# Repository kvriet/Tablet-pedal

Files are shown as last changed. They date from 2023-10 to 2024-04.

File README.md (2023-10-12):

# Tablet Foot Pedal
A foot pedal for a tablet for hands-free page turning.

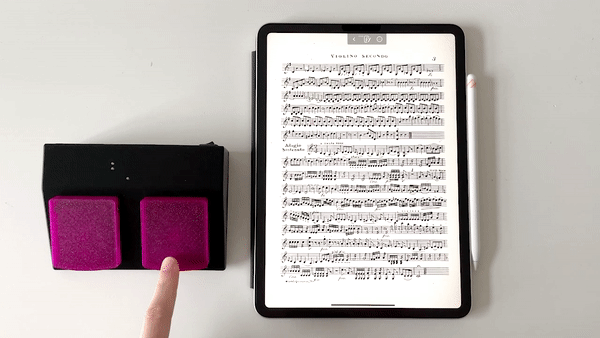
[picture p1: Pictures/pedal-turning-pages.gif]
Foot pedal connected to tablet turning pages of sheet music


## Instructions
### Pairing
The pedal has a power switch that turns on the pedal and automatically puts it in bluetooth pairing mode. When the pedal is turning on, the blue LED will flash rapidly three times. For first-time pairing, open the bluetooth menu on your sheet music device, select your pedal (Pedal Name) and agree to pair. That's all that is needed. On most devices pairing will be automatic after that.

### Power and sleep mode
To conserve energy, turn the pedal off with the black power switch when you're not using the pedal for a longer time. If you forget to switch it off, the pedal will go into deep sleep after 15 minutes. To wake the pedal up again, turn it off and on with the power switch.

How many minutes it takes before the pedal goes to sleep can be changed in the code with the timeUntilSleepMins variable.

On a single full charge, the battery should last roughly 12 hours of use.

### Low battery warning
When the battery is running low, the pedal will flash the blue LED rapidly four times. It does this every minute.
This feature can be disabled in the code by setting lowBatteryMessage to 'false'.

### Charging
The pedal runs on a 3100mAh, 18650 Li-ion battery. The battery can be charged via the micro-USB port using a common USB phone charger. When charging, the red LED will turn on. Once charging is done, the green LED will turn on.

Safety: The pedal contains a protection circuit for the battery to prevent charging and discharging too much. However, always take care with Li-ion batteries. It's best to charge them where you can keep an eye on them. For good battery health, don't leave the battery discharged for many months. Don't use the pedal in environments below 0 degrees Celsius.

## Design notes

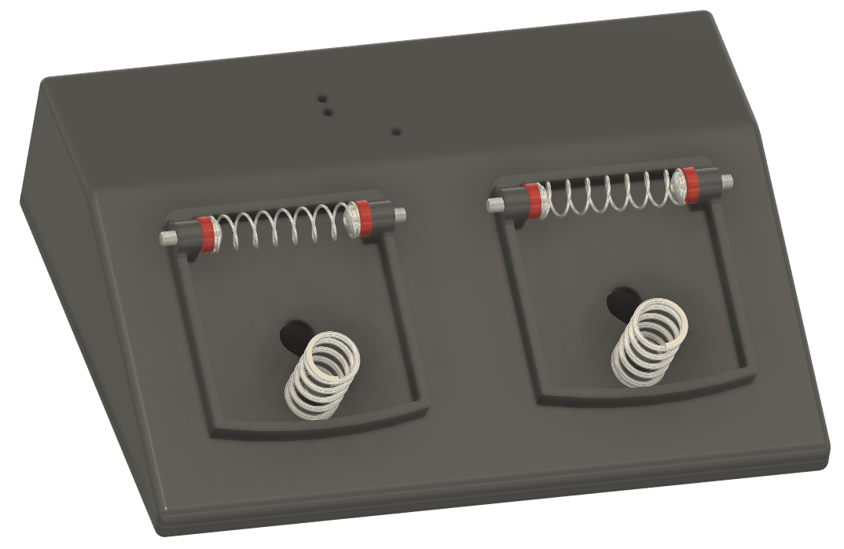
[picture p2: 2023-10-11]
Pictures/turner-without-pedals-springs-visible.png

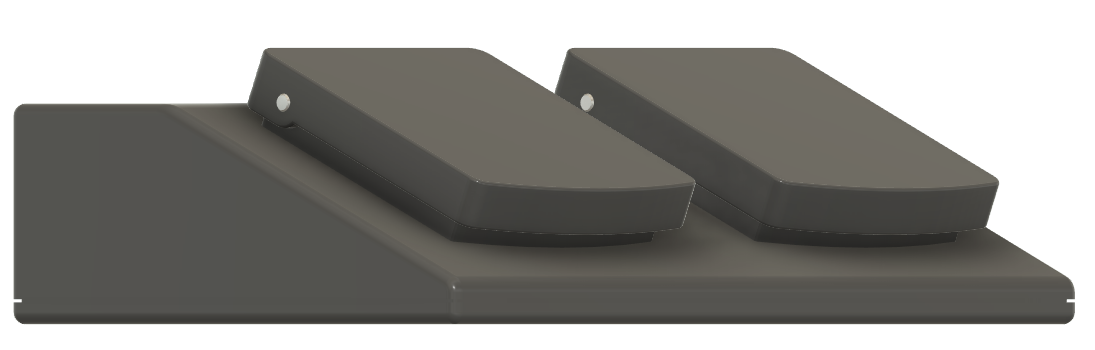
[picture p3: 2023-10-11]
Pictures/turner-corner-view-pedals.png

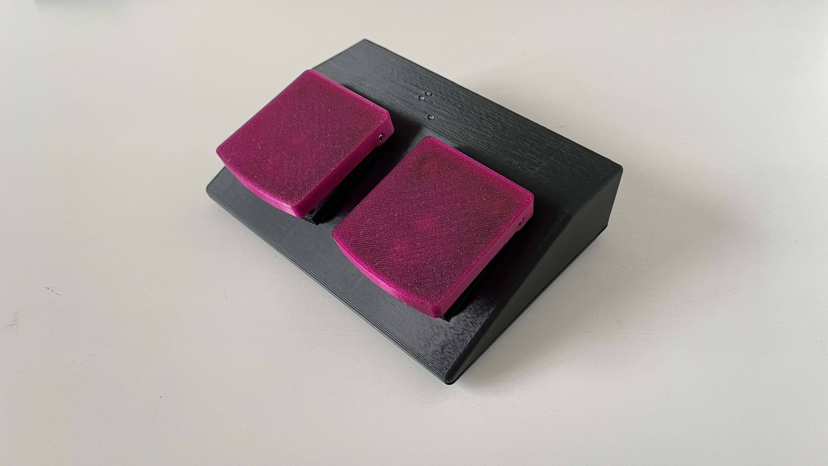
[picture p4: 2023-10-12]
Pictures/page-turner.JPG

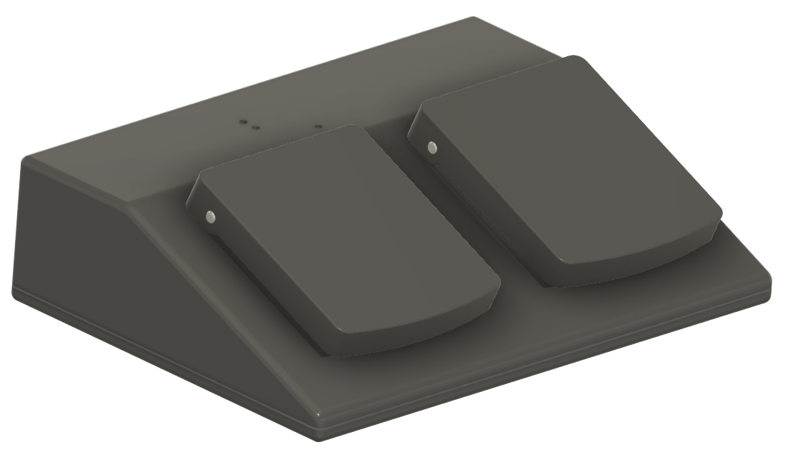
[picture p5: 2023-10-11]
Pictures/page-turner.png

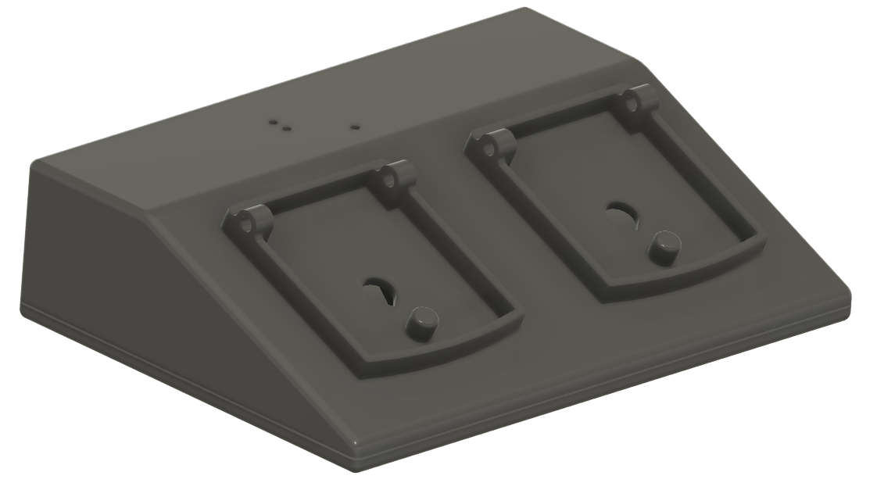
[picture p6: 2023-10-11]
Pictures/page-turner-no-pedals-no-springs.png

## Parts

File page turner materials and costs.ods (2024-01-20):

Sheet: Costs
amount | name | item | total | link to item
1 | LilyGO TTGO T-Energy ESP32-WROVER | € 8.00 | € 8.00 | https://www.aliexpress.com/item/4000453570320.html, https://www.tinytronics.nl/shop/nl/development-boards/microcontroller-boards/met-wi-fi/lilygo-ttgo-t-energy-esp32-wrover-met-18650-batterijhouder
1 | 18650 Li-ion battery | € 3.50 | € 3.50 | https://www.tinytronics.nl/shop/nl/power/batterijen/18650/eve-18650-li-ion-batterij-3100mah-10a-inr18650-33v
2 | buttons for pedal left and right Normally Open | € 0.36 | € 0.72 | https://nl.aliexpress.com/item/4000208544567.html
2 | springs 6mm x 30mm 0.6mm diameter | € 0.09 | € 0.17 | https://nl.aliexpress.com/item/1005001408318647.html
2 | springs 8mm x 20mm 0.8mm diameter | € 0.09 | € 0.18 | https://nl.aliexpress.com/item/1005001408406253.html
1 | rocker switch 8.5 x 13.5mm | € 0.45 | € 0.45 | https://www.tinytronics.nl/shop/nl/schakelaars/manuele-schakelaars/wipschakelaars/standaard-inbouw-wipschakelaar-klein
4 | screws 3mm x 10mm | € 0.03 | € 0.11 | https://www.tinytronics.nl/shop/nl/gereedschap-en-montage/installatie-en-montagemateriaal/bouten/bout-m3-10mm-draad-100-stuks
7 | screws 3mm x 5mm | € 0.03 | € 0.18 | https://www.tinytronics.nl/shop/nl/gereedschap-en-montage/installatie-en-montagemateriaal/bouten/bout-m3-5mm-draad-100-stuks
124 | filament (grams) | € 0.02 | € 2.60 | https://www.tinytronics.nl/shop/nl/3d-printen/filament/1.75mm-filament/pla/azurefilm-pla-filament-1.75mm-1kg-zwart
4 | silicone feet | € 0.02 | € 0.07 | https://www.aliexpress.com/p/shoppingcart/index.html
 |  | total | € 15.97
 |  |  |  | Picture and schematic of pushbutton (from TinyTronics):

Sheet: Sign_up
Jack
Daan

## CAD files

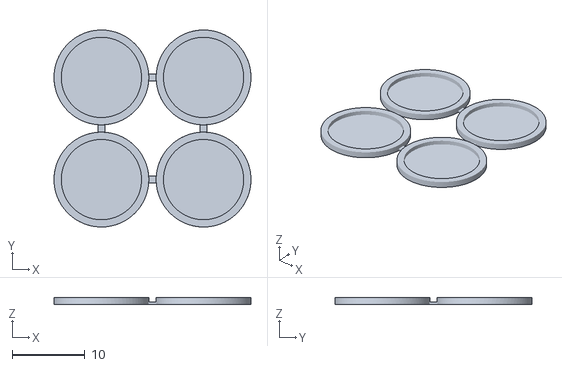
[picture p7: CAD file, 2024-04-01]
Print files/4x 10mm feet.stl
27.0 x 27.0 x 0.9

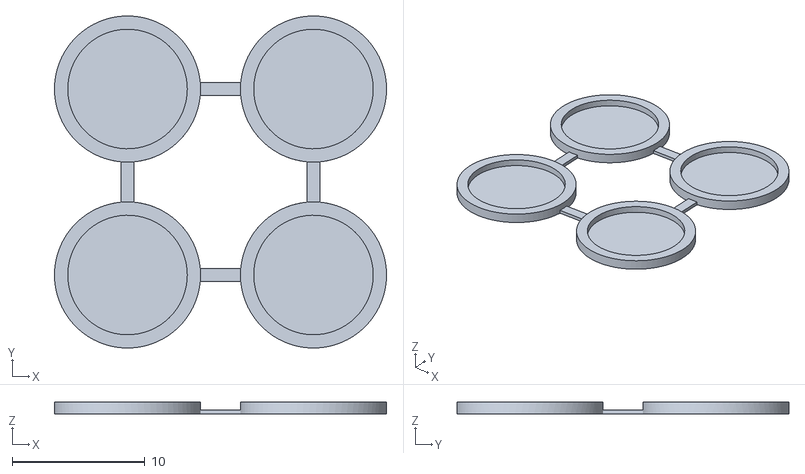
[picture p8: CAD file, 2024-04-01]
Print files/4x 8mm feet.stl
25.0 x 25.0 x 0.9

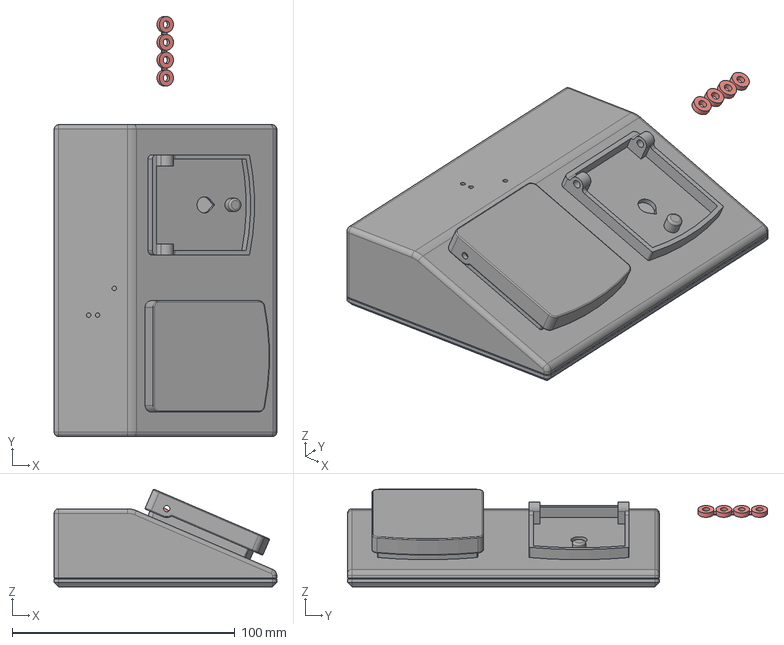
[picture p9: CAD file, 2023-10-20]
Print files/page turner STEP file.step
100.0 x 188.6 x 43.8 mm

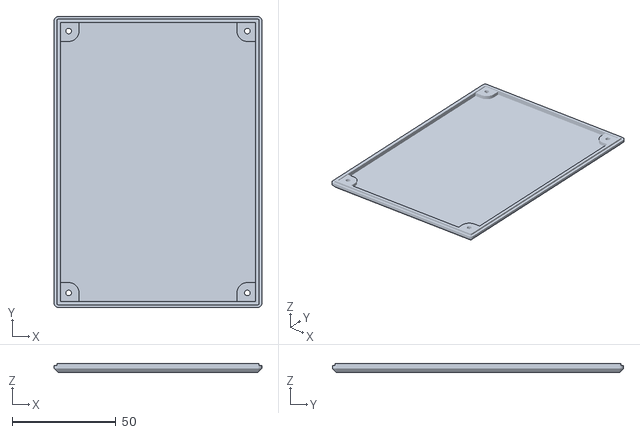
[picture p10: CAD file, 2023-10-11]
Print files/page turner bottom v3.stl
100.0 x 140.0 x 4.50

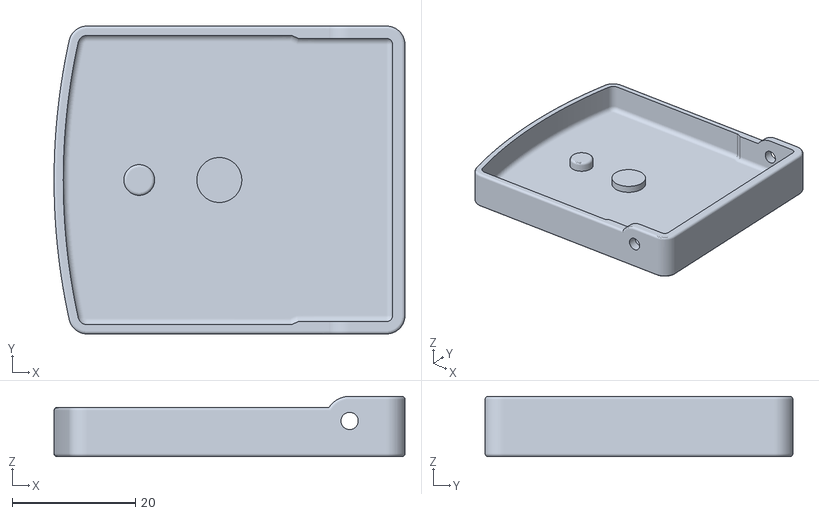
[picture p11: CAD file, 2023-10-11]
Print files/pedal v4.stl
57.0 x 50.0 x 9.80

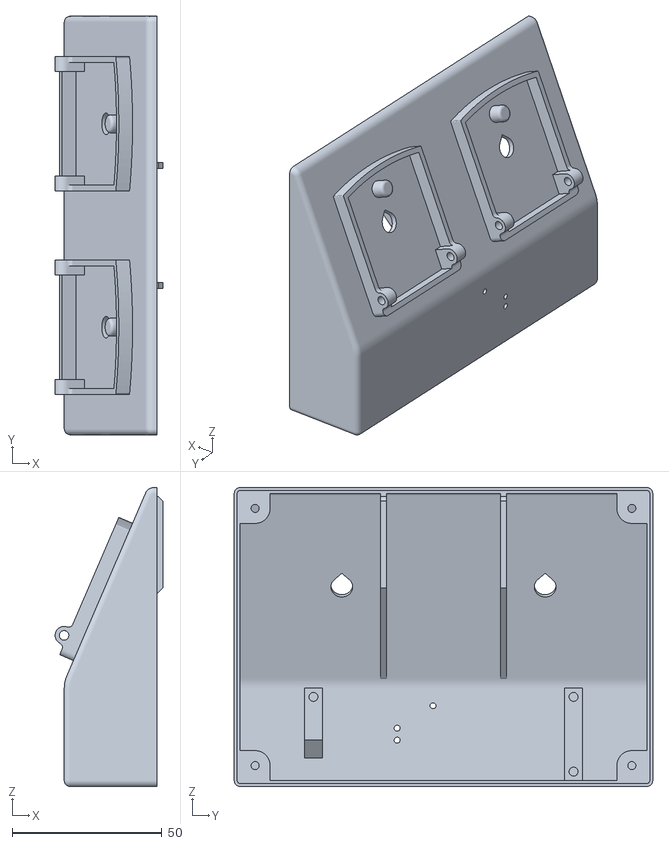
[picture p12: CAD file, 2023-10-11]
Print files/page turner top v4.stl
36.1 x 140.0 x 100.0

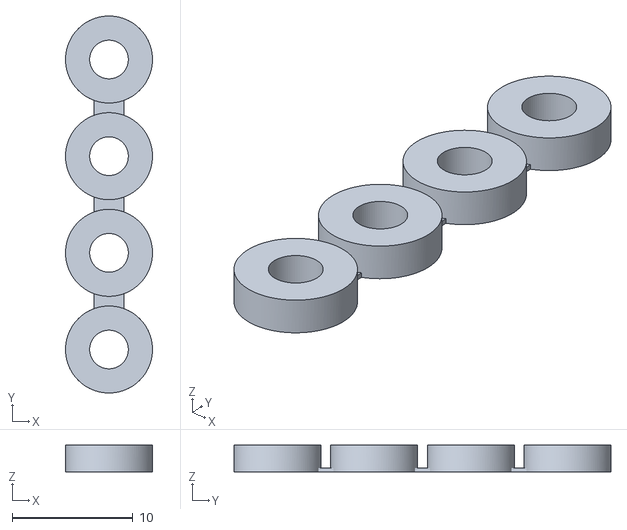
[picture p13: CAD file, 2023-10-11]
Print files/axle washer 3.4mm 4x strip v2.stl
7.20 x 31.2 x 2.20

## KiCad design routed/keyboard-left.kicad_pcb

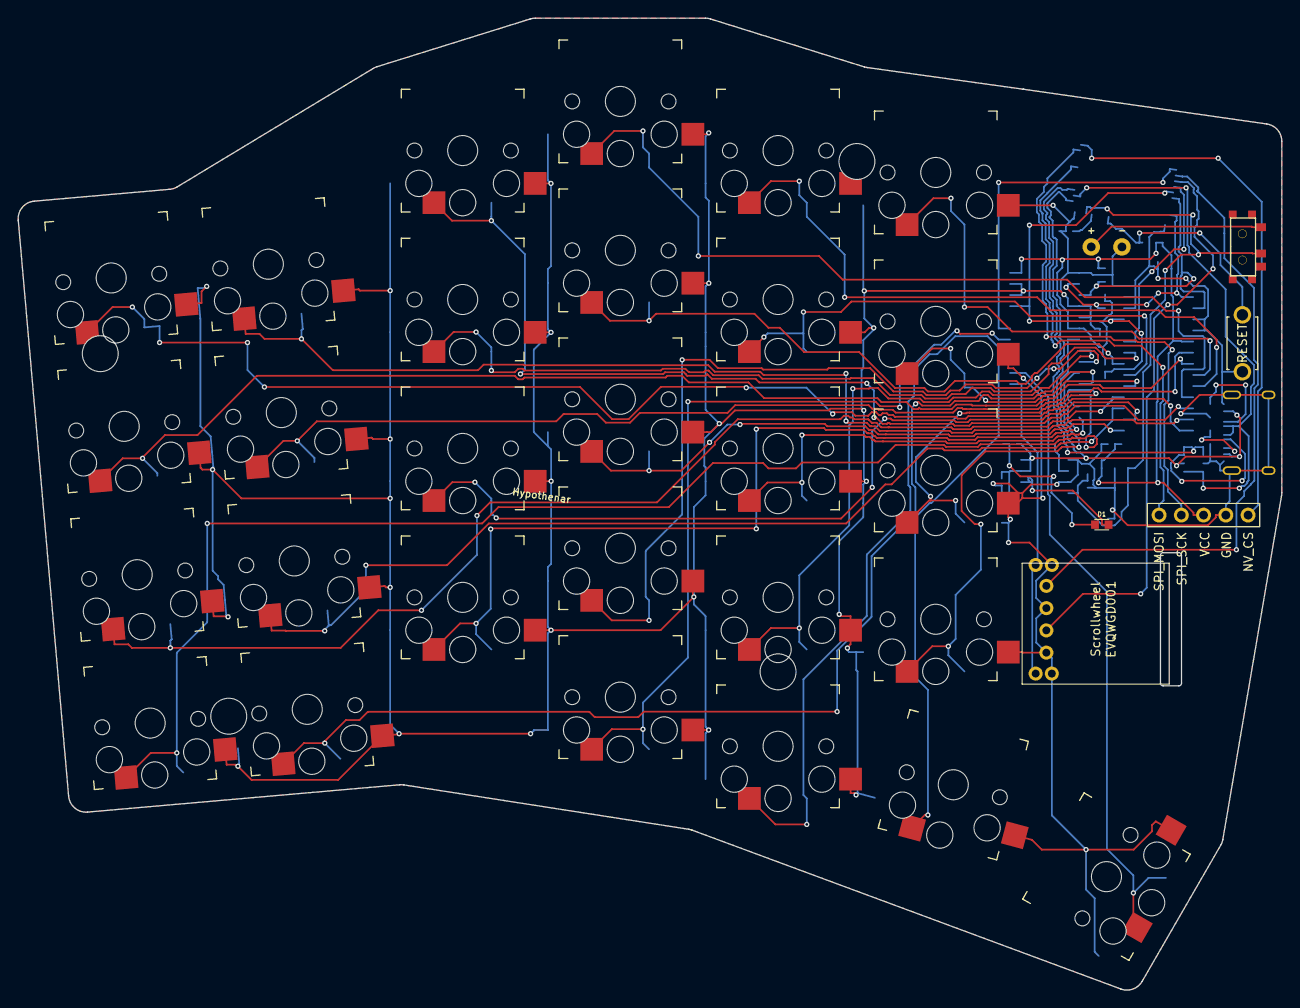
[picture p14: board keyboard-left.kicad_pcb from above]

Board: 2 copper layers, 144.2 x 110.9 mm, 60 parts (0 on the bottom side), 50 nets.

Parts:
19.051: ms88sf3
19.052, 19.053: MCP23017; MCP23017_SOIC-28W
19.054: USB_C_Receptacle_HRO_TYPE-C-31-M-12
19.055: USBLC6-2SC6; USBLC6-2SC6_SOT-23-6
19.056: TP4056; TP4056_SOP-8
19.057: XC6206P332MR; XC6206_SOT-89-3
BT1: BATTERY; battery_pads
DISP1: display_nice_view
P1: C1; passive_0603
P2: C2; passive_0603
P3: C3; passive_0603
P4: C4; passive_0603
P5: C5; passive_0603
P6: C6; passive_0603
P7: C7; passive_0603
P8: C8; passive_0603
P9: R1; passive_0603
P10: R2; passive_0603
P11: R3; passive_0603
P12: R4; passive_0603
P13: R5; passive_0603
P14: R6; passive_0603
P15: R7; passive_0603
P16: R8; passive_0603
P17: D1; passive_0603
S1, S2, S3, S4, S5, S6, S7, S8, S9, S10, S11, S12, S13, S14, S15, S16, S17, S18, S19, S20, S21, S22, S23, S24, S25, S26, S27, S28: PG1350
T1: SPDT_C128955
_1: ResetSW
_2, _3, _4, _5: Hole

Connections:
CHARGE_ACTIVE: 19.056.6, P17.2
CHG_LED: P16.2, P17.1
GND: 19.051.1, 19.051.18, 19.051.34, 19.052.10, 19.052.11, 19.052.14, 19.052.15, 19.052.16, 19.052.17, 19.053.10, 19.053.11, 19.053.14, 19.053.16, 19.053.17, 19.054.A1, 19.054.A12, 19.054.B1, 19.054.B12, 19.054.SH, 19.055.2, 19.056.1, 19.056.3, 19.057.2, BT1.2, DISP1.4, P1.2, P2.2, P3.2, P4.2, P5.2, P6.2, P7.2, P8.2, P11.2, P12.2, P13.2, S1.2, S2.2, S3.2, S4.2, S5.2, S6.2, S7.2, S8.2, S9.2, S10.2, S11.2, S12.2, S13.2, S14.2, S15.2, S16.2, S17.2, S18.2, S19.2, S20.2, S21.2, S22.2, S23.2, S24.2, S25.2, S26.2, S27.2, S28.2, _1.2
I2C_RESET: 19.051.13, 19.052.18, 19.053.18, P14.2
I2C_SCL: 19.051.14, 19.052.12, 19.053.12, P9.2
I2C_SDA: 19.051.17, 19.052.13, 19.053.13, P10.2
MCP_A_INT: 19.051.12, 19.052.20
MCP_B_INT: 19.051.9, 19.053.20
NV_CS: 19.051.45, DISP1.5
PROG: 19.056.2, P13.1
RESET: 19.051.28, P15.2, _1.1
SPI_MOSI: 19.051.41, DISP1.1
SPI_SCK: 19.051.44, DISP1.2
USB_CC1: 19.054.A5, P11.1
USB_CC2: 19.054.B5, P12.1
USB_DM: 19.051.36, 19.054.A7, 19.054.B7, 19.055.3, 19.055.4
USB_DP: 19.051.37, 19.054.A6, 19.054.B6, 19.055.1, 19.055.6
VBAT: 19.051.32, 19.056.4, 19.057.1, P3.1, P4.1, T1.2
VBAT_SW: BT1.1, T1.1
VBUS: 19.051.35, 19.054.A4, 19.054.A9, 19.054.B4, 19.054.B9, 19.055.5, 19.056.7, 19.056.8, P1.1, P2.1, P16.1
VCC: 19.052.9, 19.053.9, 19.053.15, 19.057.3, DISP1.3, P5.1, P7.1, P8.1, P9.1, P10.1, P14.1, P15.1
VDD_MCU: 19.051.31, P6.1
sw_matrix_index_bottom: 19.053.7, S19.1
sw_matrix_index_home: 19.053.1, S20.1
sw_matrix_index_mod: 19.053.22, S18.1
sw_matrix_index_num: 19.052.5, S22.1
sw_matrix_index_top: 19.052.23, S21.1
sw_matrix_inner_bottom: 19.053.8, S23.1
sw_matrix_inner_home: 19.053.2, S24.1
sw_matrix_inner_num: 19.052.6, S26.1
sw_matrix_inner_top: 19.052.24, S25.1
sw_matrix_middle_bottom: 19.053.6, S14.1
sw_matrix_middle_home: 19.052.28, S15.1
sw_matrix_middle_mod: 19.053.21, S13.1
sw_matrix_middle_num: 19.052.4, S17.1
sw_matrix_middle_top: 19.052.22, S16.1
sw_matrix_outer_bottom: 19.053.3, S1.1
sw_matrix_outer_home: 19.052.25, S2.1
sw_matrix_outer_num: 19.052.1, S4.1
sw_matrix_outer_top: 19.052.7, S3.1
sw_matrix_pinky_bottom: 19.053.4, S5.1
sw_matrix_pinky_home: 19.052.26, S6.1
sw_matrix_pinky_num: 19.052.2, S8.1
sw_matrix_pinky_top: 19.052.8, S7.1
sw_matrix_ring_bottom: 19.053.5, S9.1
sw_matrix_ring_home: 19.052.27, S10.1
sw_matrix_ring_num: 19.052.3, S12.1
sw_matrix_ring_top: 19.052.21, S11.1
sw_thumbs_layer_cluster: 19.053.23, S27.1
sw_thumbs_space_cluster: 19.053.24, S28.1

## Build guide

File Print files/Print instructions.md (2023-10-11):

# Print instructions

Print in layer height 0.28 or 0.3mm. Use the print orientation as supplied in the STLs. There's no need for supports, but using a brim for the page turner top and axle washers is a good idea to prevent the prints from warping or coming off the printbed.

The washers might be too loose or tight on your printer. Try scaling the washers up or down a little to make them screw onto the bolts nicely.

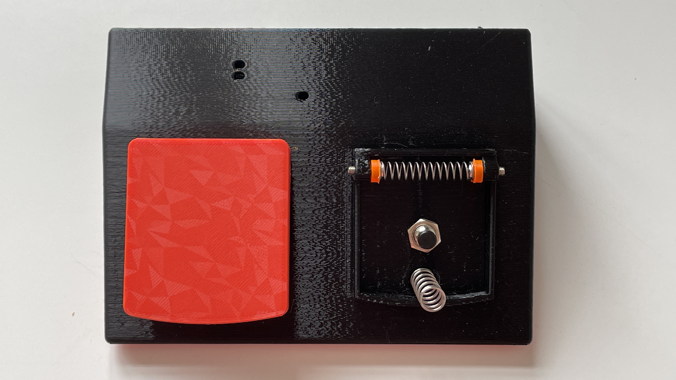
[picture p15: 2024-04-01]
Assembly/pedal assembly.jpg

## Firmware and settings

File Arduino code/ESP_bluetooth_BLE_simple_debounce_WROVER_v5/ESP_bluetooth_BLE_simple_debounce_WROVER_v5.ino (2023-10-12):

/*
 Katrien van Riet - September 2023 - v5.5
 Keyboard code from: https://github.com/T-vK/ESP32-BLE-Keyboard
 Code for ESP32 WROVER version (board T18_3.0). Choose board: ESP32 Wrover Kit (all versions)
 If your board manager doesn't show the WROVER board, put this URL under "Additional boards manager URLs" in Preferences:
 https://raw.githubusercontent.com/espressif/arduino-esp32/gh-pages/package_esp32_index.json
 */

#include <BleKeyboard.h>
#include <driver/adc.h>
#include "esp_adc_cal.h"

//// VARIABLES YOU CAN CHANGE ////
BleKeyboard bleKeyboard("Pedal Page Turner", "CM van Riet", 100);
// ("Bluetooth Device Name", "Bluetooth Device Manufacturer", initial battery level of your device)
// You can change the bluetooth device name to suit your own needs

bool printToSerial = false;                   // Set to 'true' to print debugging statements to serial port
bool lowBatteryMessage = true;                // Set to 'false' to disable LED flashing when battery is low
unsigned int timeUntilSleepMins = 15;         // Time in minutes until device goes to sleep
unsigned int batteryMeasureIntervalMins = 1;  // Time in minutes between battery level readings


//// THINGS THAT SHOULD BE LEFT ALONE ////
const int LEFT_PIN = 2;
const int RIGHT_PIN = 4;
const int LED_PIN = 5;
const int VOLTAGE_DIVIDER_PIN = 14;  // Not sure what this pin does, but for battery voltage reading, it needs to be HIGH
                                     // To conserve energy, pin 14 is kept LOW when not reading battery voltage level
const int BATTERY_LEVEL_PIN = 35;
const int debounceTime = 15;  // Debounce time in millis for buttons
bool flagLeft = false;
bool flagRight = false;
bool lowBattery = false;
unsigned long int timeMultiplier = 60000;      // Multiplier from mins to millis = 60 * 1,000
unsigned long int prevTimeSleep = 0;           // In millis
unsigned long int prevTimeBatteryMeasure = 0;  // In millis
unsigned long int prevTimeLeft = 0;            // In millis
unsigned long int prevTimeRight = 0;           // In millis
int buttonStateLeft;
int lastButtonStateLeft = LOW;
int buttonStateRight;
int lastButtonStateRight = LOW;

void setup() {
  pinMode(LED_PIN, OUTPUT);
  pinMode(LEFT_PIN, INPUT_PULLUP);
  pinMode(RIGHT_PIN, INPUT_PULLUP);
  pinMode(VOLTAGE_DIVIDER_PIN, OUTPUT);

  digitalWrite(VOLTAGE_DIVIDER_PIN, LOW);  // Preserve energy

  startupLED();  // Show startup LED sequence
  bleKeyboard.begin();

  if (printToSerial) Serial.begin(115200);
  if (printToSerial) Serial.println("Starting BLE!");

  // Two statements below are needed for battery measurement
  esp_adc_cal_characteristics_t adc_chars;
  esp_adc_cal_value_t val_type = esp_adc_cal_characterize((adc_unit_t)ADC_UNIT_1, (adc_atten_t)ADC_ATTEN_DB_2_5, (adc_bits_width_t)ADC_WIDTH_BIT_12, 1100, &adc_chars);
}

void loop() {
  unsigned long int currentTime = millis();  // Current time in millis

  if ((currentTime - prevTimeSleep) > timeUntilSleepMins * timeMultiplier) {
    // Board goes to deep sleep if no buttons are pressed for a certain time
    if (printToSerial) Serial.println("Entering deep sleep now!");
    esp_deep_sleep_start();
  }

  if (bleKeyboard.isConnected()) {
    // If pedal is paired through bluetooth, buttons will be read
    doButtons(currentTime);
  }

  if ((currentTime - prevTimeBatteryMeasure) > batteryMeasureIntervalMins * timeMultiplier) {
    // This function reads the battery level every few minutes
    readBatteryLevel();
    if (lowBattery && lowBatteryMessage) {
      lowBatteryLED();
    }
    prevTimeBatteryMeasure = currentTime;
  }

  delay(20);  // Small delay to save energy (don't increase further than 50!)
}

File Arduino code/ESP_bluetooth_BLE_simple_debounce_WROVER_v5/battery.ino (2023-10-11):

void readBatteryLevel() {
  // Function to read battery level
  digitalWrite(VOLTAGE_DIVIDER_PIN, HIGH);  // This pin needs to be pulled HIGH before battery voltage can be read
  delay(1);
  float measurement = (float)analogRead(BATTERY_LEVEL_PIN);
  float batteryVoltage = (measurement / 4095.0) * 7.26;  // Convert pin reading to battery voltage
  digitalWrite(VOLTAGE_DIVIDER_PIN, LOW);                // Set pin low to conserve energy
  if (printToSerial) Serial.println(batteryVoltage);
  if (batteryVoltage < 3.7) lowBattery = true;  // If battery voltage drops below 3.5V, set low battery flag, which will turn on low battery LED sequence
  else lowBattery = false;
}

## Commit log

2023-10-11 First upload project
    [Pedal turner circuit.kicad_pcb, Pedal turner circuit.kicad_sch, axle washer 3.4mm 4x strip v2.stl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]
2023-10-11 Added Arduino code
2023-10-11 Added print instructions
    [page turner top v4.stl]
2023-10-11 Update Print instructions.md
2023-10-11 Updated version (added details)
    [pedal turner materials and costs.ods]
2023-10-11 updated spreadsheet name
    [page turner materials and costs.ods]
2023-10-11 Changed fillet edge to chamfer in bottom print
    [page turner bottom v2.stl, page turner bottom v3.stl]
2023-10-12 Updated Arduino code v5
    - Added board manager URL for ESP32 boards
    - Added comment on how to change bluetooth device name
2023-10-20 Create page turner STEP file.step
    [page turner STEP file.step]
2023-12-17 Update page turner materials and costs.ods
    Fixed unclear description for button Normally Open
    [page turner materials and costs.ods]
2024-01-20 Update page turner materials and costs.ods
    [page turner materials and costs.ods]
2024-04-01 added assembly pictures
2024-04-01 minor update circuits
2024-04-01 added print feet rings
    print feet rings that can be glued onto the bottom and prevent the silicone feet from slipping off
    [4x 10mm feet.stl, 4x 8mm feet.stl]
2024-05-09 Create Pedal turner circuit-2024-05-03_115710.zip
